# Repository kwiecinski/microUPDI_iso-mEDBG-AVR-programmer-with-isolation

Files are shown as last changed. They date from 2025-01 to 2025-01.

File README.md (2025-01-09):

# microUPDI\_iso

DIY UPDI programmer with additional data line isolators, allowing you to safely work on high-voltage (HV) projects.

This project is based on the original [microUPDI project by MCUdude](https://github.com/MCUdude/microUPDI),\
and the firmware is sourced from [microUPDIcore](https://github.com/MCUdude/microUPDIcore).

<div style="display: flex; justify-content: space-around; align-items: center;">
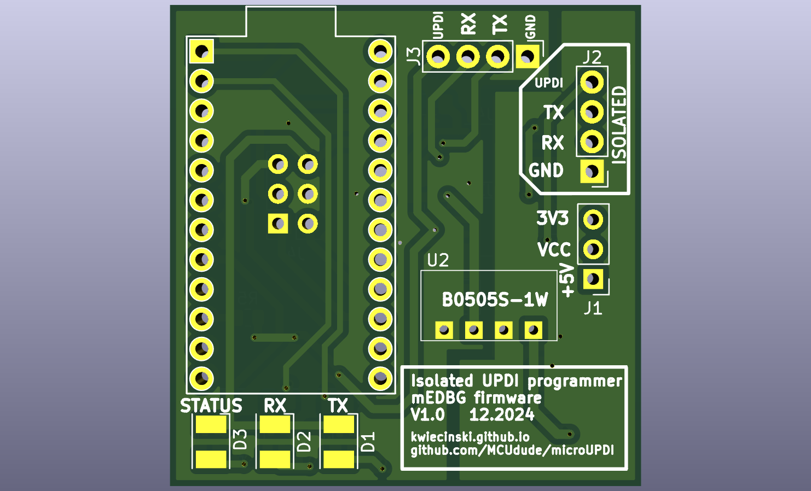
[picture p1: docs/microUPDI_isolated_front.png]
microUPDI front
    
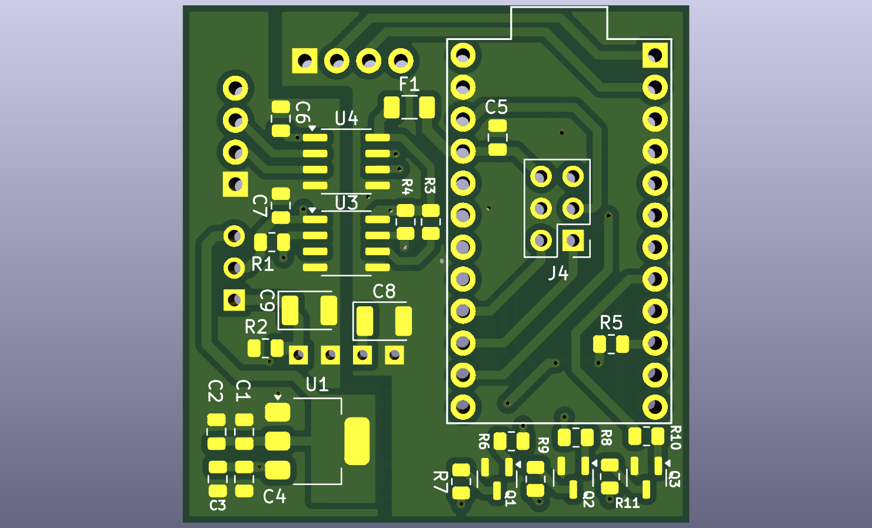
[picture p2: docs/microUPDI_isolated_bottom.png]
microUPDI bottom
    
</div>

---

### IMPORTANT

You might find references stating that the mEDBG programmer supports the AVR-Dx series of microcontrollers:\
[Microchip Device Support Documentation](https://packs.download.microchip.com/DeviceDoc/Device_Support.pdf).

However, **this is not true!** The microUPDI programmer does not support the AVR-Dx series. It is compatible only with the megaAVR-0 and tinyAVR-0/1/2 series. All device and firmware updates are available from the Microchip Packs website, but the mEDBG has not seen significant updates in years.

---

### Hardware

The microUPDI programmer is built on the **Pro Micro 5V/16MHz** board, which uses the ATmega32U4 microcontroller. I purchased it cheaply from China, and it works just fine.

To isolate the data and power lines, you need the following components:

- **ADuM1250**: A bidirectional digital data isolator for the UPDI interface.
- **ADuM1281**: A dual-channel isolator for UART RX and TX lines.

For UART, any isolator capable of handling these lines will suffice; it doesn’t have to be the ADuM1281 specifically. However, for UPDI, the isolator must support bidirectional communication. I tested the ADuM1250 (designed for I²C), and it works correctly in this context.

---

### Software

#### Flashing the Firmware

The original method suggested by MCUdude involves using the Arduino IDE to upload `.hex` and `.eep` files to the Pro Micro board using the bootloader. Unfortunately, I encountered compilation issues with this approach.

Instead, I used **avrdude** to program the board. Ensure you are using the latest version of avrdude.

---

#### Checking the Bootloader

Before proceeding, identify the bootloader type on your Pro Micro board.\
To program the board using the bootloader, you need to reset the Pro Micro. After resetting, a new COM port will appear:

- For example, the board might normally use `COM11`, but after a reset, you’ll see `COM12` for the bootloader.

To extend the bootloader activation time, use the **double-reset** method. Quickly reset the board twice, and you’ll have 8 seconds (instead of the default 3 seconds) to upload the firmware.\
[Learn more about the Pro Micro bootloader here](https://learn.sparkfun.com/tutorials/pro-micro--fio-v3-hookup-guide/troubleshooting-and-faq).

---

#### Using avrdude

Run the following command to verify communication with the board:

```bash
avrdude.exe -C avrdude.conf -c avr109 -P COM12 -patmega32u4 -v
```

Explanation of the parameters:

- `-v`: Enables verbose mode for detailed output.
- `-c avr109`: Specifies the bootloader protocol (Caterina in this case).
- `-P COM12`: Selects the bootloader COM port.

If communication is successful, you’ll see details about the device signature and bootloader. If you encounter a “not in sync” error, your bootloader might differ or require alternative settings.

For me, the bootloader type was `avr109`.

For more options, consult the [avrdude documentation](https://avrdudes.github.io/avrdude/7.3/avrdude_4.html).

---

#### Using the Load\_firmware.bat Script

You can use a slightly modified version of MCUdude’s script to load the firmware.

Update the script with the paths to `avrdude.exe` and `avrdude.conf`:

```bat
SET AVRDUDE_PATH=avrdude.exe
SET AVRDUDE_CONF_PATH=avrdude.conf
```

Set the programmer type based on your bootloader:

```bat
SET PROGRAMMER=avr109
```

Specify the COM port that appears after resetting the board:

```bat
SET EXTRA_FLAGS=-P COM12 -b57600
```

Target-specific settings:

```bat
SET TARGET=atmega32u4
SET FLASH_FILE=mEDBG_UPDI.hex
SET EEPROM_FILE=mEDBG_UPDI.eep
```

Make sure all files are in the same directory as the `Load_firmware.bat` script.

---

#### Example Output

If everything is configured correctly, you should see output like this:

```plaintext
Programmer Type : butterfly
Description     : Atmel AppNote AVR109 Boot Loader

Connecting to programmer: .
Found programmer: Id = "CATERIN"; type = S
    Software Version = 1.0; No Hardware Version given.
Programmer supports auto addr increment.
Programmer supports buffered memory access with buffersize=128 bytes.

Programmer supports the following devices:
    Device code: 0x44

avrdude.exe: devcode selected: 0x44
avrdude.exe: AVR device initialized and ready to accept instructions

Reading | ################################################## | 100% 0.00s

avrdude.exe: Device signature = 0x1e9587 (probably m32u4)
avrdude.exe: safemode: hfuse reads as D8
avrdude.exe: safemode: efuse reads as CB

avrdude.exe: safemode: Fuses OK (E:CB, H:D8, L:FF)

avrdude.exe done.  Thank you.
```

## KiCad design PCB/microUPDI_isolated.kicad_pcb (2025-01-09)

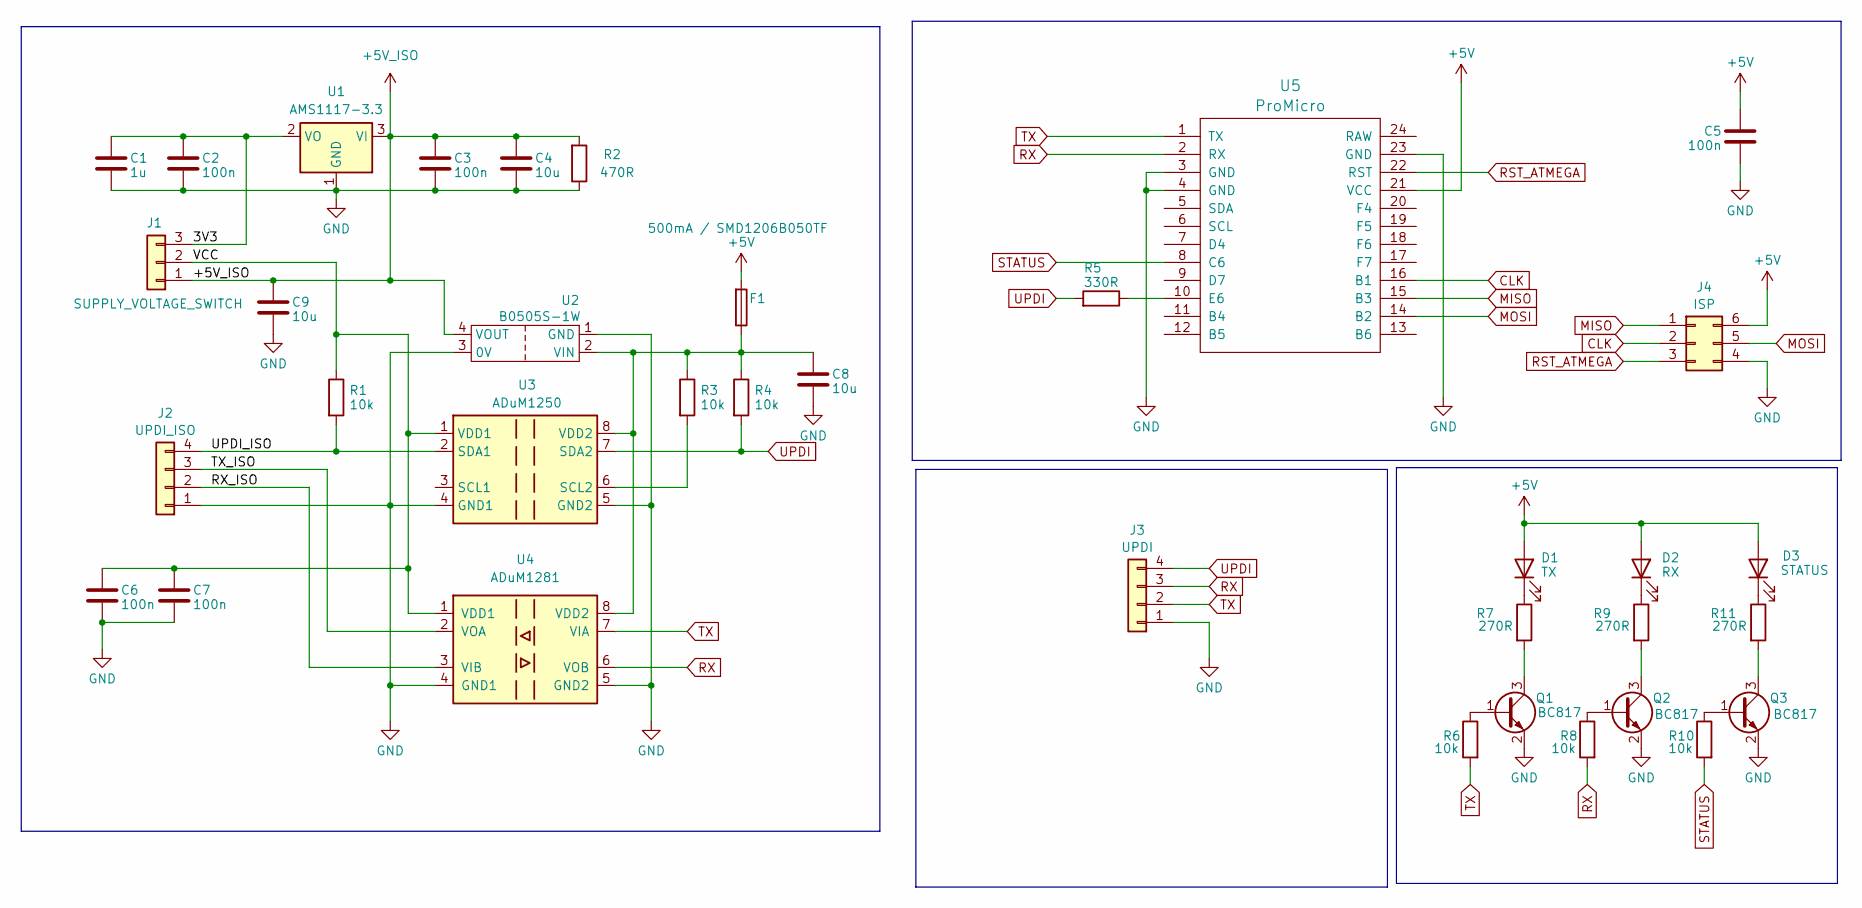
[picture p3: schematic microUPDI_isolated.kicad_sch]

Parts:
C1: 1u; C_0805_2012Metric
C2, C3, C5, C6, C7: 100n; C_0805_2012Metric
C4: 10u; C_0805_2012Metric
C8, C9: 10u; CP_EIA-3528-21_Kemet-B
D1: TX; LED_PLCC-2_3.4x3.0mm_AK
D2: RX; LED_PLCC-2_3.4x3.0mm_AK
D3: STATUS; LED_PLCC-2_3.4x3.0mm_AK
F1: 500mA / SMD1206B050TF; Fuse_1206_3216Metric
J1: SUPPLY_VOLTAGE_SWITCH; PinHeader_1x03_P2.54mm_Vertical
J2: UPDI_ISO; PinHeader_1x04_P2.54mm_Vertical_littleBigger
J3: UPDI; PinHeader_1x04_P2.54mm_Vertical_littleBigger
J4: ISP; PinHeader_2x03_P2.54mm_Vertical
Q1, Q2, Q3: BC817; SOT-23
R1, R3, R4, R6, R8, R10: 10k; R_0805_2012Metric
R2: 470R; R_0805_2012Metric
R5: 330R; R_0805_2012Metric
R7, R9, R11: 270R; R_0805_2012Metric
U1: AMS1117-3.3; SOT-223-3_TabPin2
U2: B0505S-1W; B0505S
U3: ADuM1250; SOIC-8_3.9x4.9mm_P1.27mm
U4: ADuM1281; SOIC-8_3.9x4.9mm_P1.27mm
U5: ProMicro

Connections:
+5V: C5.1, D1.2 (A), D2.2 (A), D3.2 (A), F1.2, J4.6, U5.21 (VCC)
+5V_ISO: C3.1, C4.1, C9.1, J1.1, R2.2, U1.3 (VI), U2.4 (VOUT)
/3V3: C1.1, C2.1, J1.3, U1.2 (VO)
/RX_ISO: J2.2, U4.3 (VIB)
/TX_ISO: J2.3, U4.2 (VOA)
/UPDI_ISO: J2.4, R1.2, U3.2 (SDA1)
/VCC: C6.1, C7.1, J1.2, R1.1, U3.1 (VDD1), U4.1 (VDD1)
CLK: J4.2, U5.16 (B1)
GND: C1.2, C2.2, C3.2, C4.2, C5.2, C6.2, C7.2, C8.2, C9.2, J2.1, J3.1, J4.4, Q1.2 (E), Q2.2 (E), Q3.2 (E), R2.1, U1.1 (GND), U2.1 (GND), U2.3 (0V), U3.4 (GND1), U3.5 (GND2), U4.4 (GND1), U4.5 (GND2), U5.3 (GND), U5.4 (GND), U5.23 (GND)
MISO: J4.1, U5.15 (B3)
MOSI: J4.5, U5.14 (B2)
unnamed: D1.1 (K), R7.1
unnamed: D2.1 (K), R9.1
unnamed: D3.1 (K), R11.1
unnamed: Q1.1 (B), R6.1
unnamed: Q1.3 (C), R7.2
unnamed: Q2.1 (B), R8.1
unnamed: Q2.3 (C), R9.2
unnamed: Q3.1 (B), R10.1
unnamed: Q3.3 (C), R11.2
unnamed: C8.1, F1.1, R3.1, R4.1, U2.2 (VIN), U3.8 (VDD2), U4.8 (VDD2)
unnamed: R3.2, U3.6 (SCL2)
unnamed: R5.1, U5.10 (E6)
RST_ATMEGA: J4.3, U5.22 (RST)
RX: J3.3, R8.2, U4.6 (VOB), U5.2 (RX)
STATUS: R10.2, U5.8 (C6)
TX: J3.2, R6.2, U4.7 (VIA), U5.1 (TX)
UPDI: J3.4, R4.2, R5.2, U3.7 (SDA2)

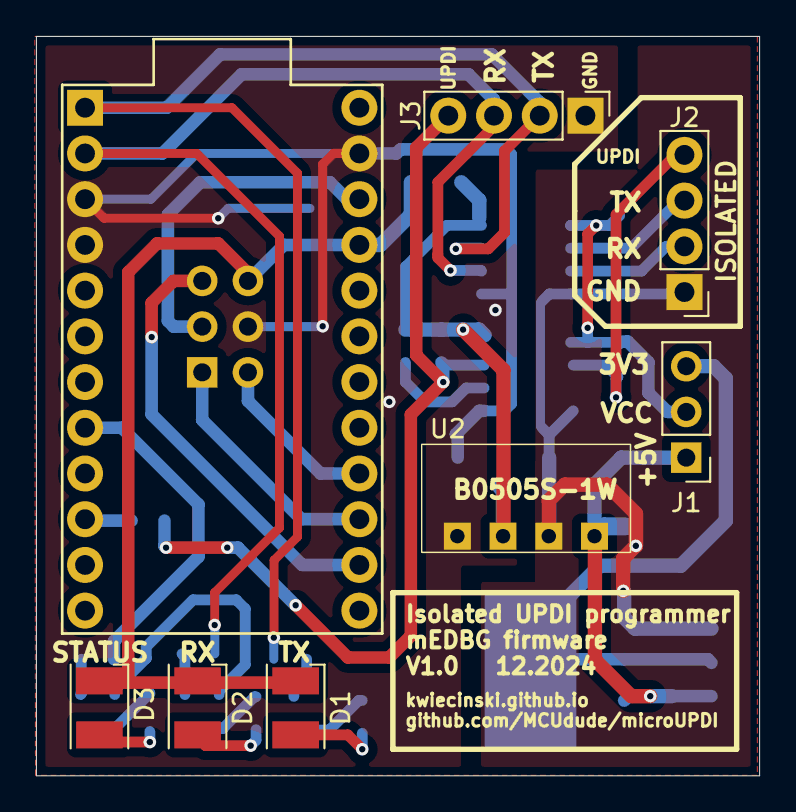
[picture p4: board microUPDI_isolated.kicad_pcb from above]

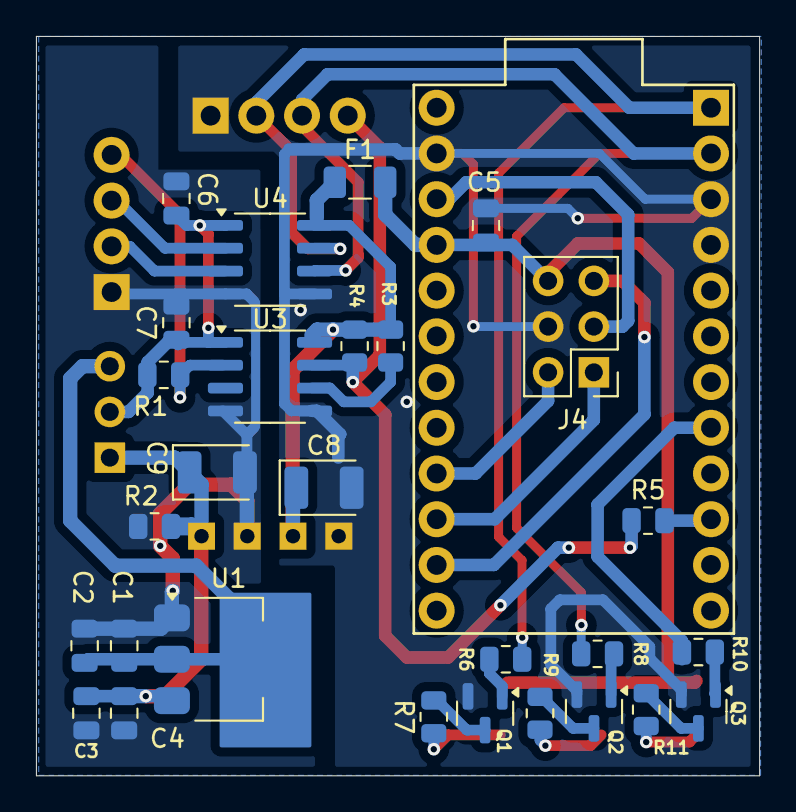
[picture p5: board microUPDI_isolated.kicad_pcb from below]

Board: 2 copper layers, 40.2 x 41.1 mm, 36 parts (28 on the bottom side), 28 nets.
